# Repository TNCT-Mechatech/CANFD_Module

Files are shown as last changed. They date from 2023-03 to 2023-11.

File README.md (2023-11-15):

# CANFD_Module
SPI->CAN FDに変換するモジュール

名前:ひなた
※画像は最新のものと比較すると古い部分があります．git pullして基板データを確認してください．
<br>

<br>

PCBAは[production/PCBA](production/PCBA)を参照してJLCPCBに発注してください．

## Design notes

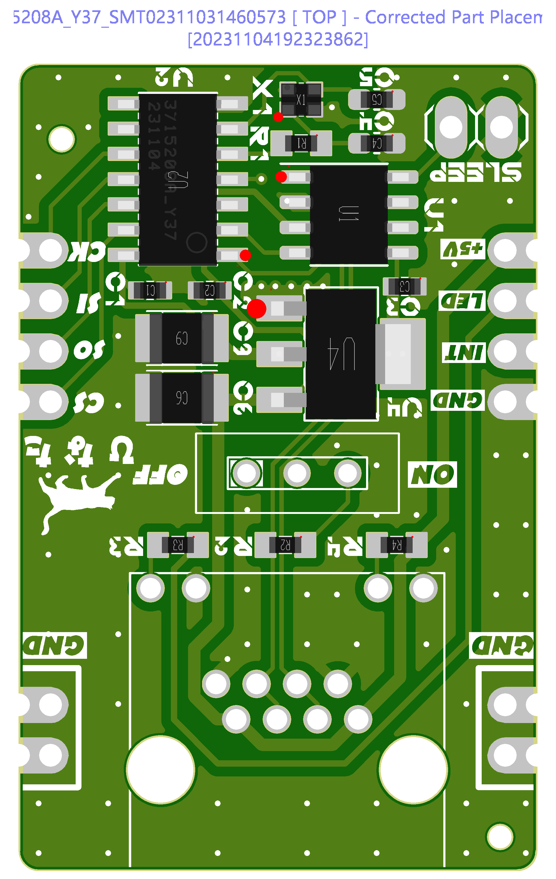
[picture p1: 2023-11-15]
production/PCBA/Produce_DanZhi.SMT_Snapshot.Top.3715208A_Y37.SMT02311031460573.png

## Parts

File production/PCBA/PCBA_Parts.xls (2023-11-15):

Comment | Designator | Footprint | JLCPCB Part # | 黄色で示す部品は名前間違ってます
MCP2517FD | U2 | MCP2517FD | C512185 | JLCPCB Partの欄に書かれている部品が正しいです
AZ1117CH-3.3TRG1 | U4 | AZ1117C | C92102 | JLCPCB Partの欄の部品で発注してください．
120Ω | R2 | CR0603 | C22787
0 | R1 | CR0603 | C21189
150 | R3,R4 | CR0603 | C22808
GRM32ER71E226KE15 | C6,C9 | 3225M | C21397
GRM0225C1E6R0BA03L | C4,C5 | 0603 | C426066
XRCGB40M000F4M01R0 | X1 | XRCGB40M000F4M00R0 | C485379
GCM188L81H104KA57 | C1,C2,C3 | GCM188L81H104KA57 | C161181
MCP2558FD | U1 | SOP-8_3.9x4.9mm_P1.27mm | C124015

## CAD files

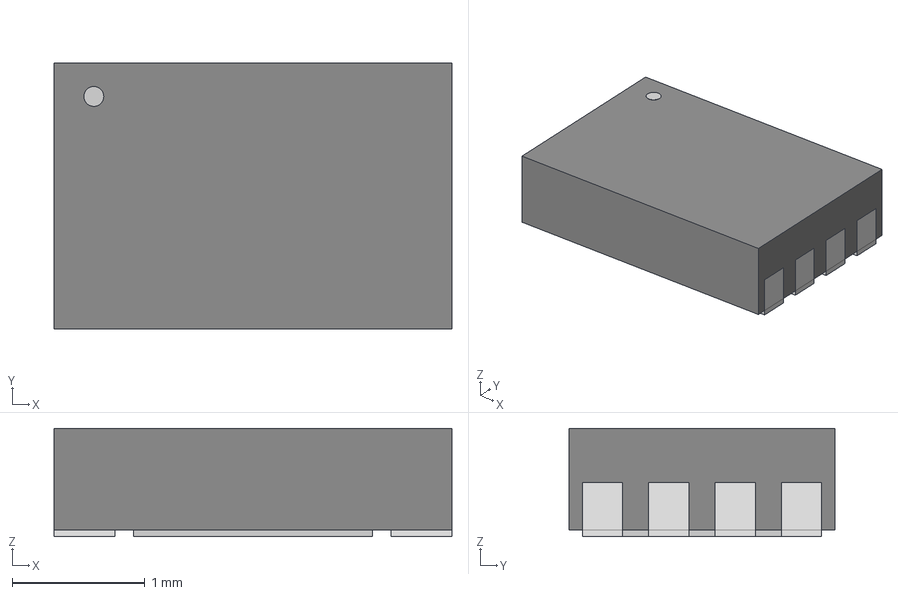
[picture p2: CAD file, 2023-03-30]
3dmodels/TDFN8_MNY_MCH.step
3.00 x 2.01 x 0.815 mm

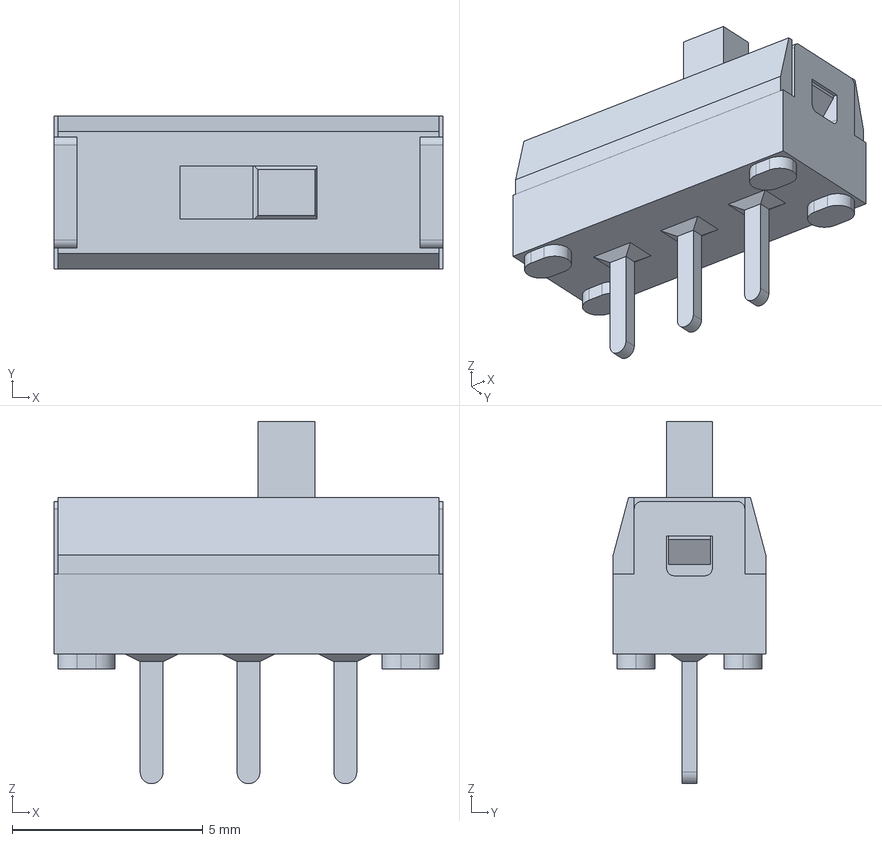
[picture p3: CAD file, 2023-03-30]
3dmodels/ss-12sdp2.stp
10.2 x 4.00 x 9.50 mm

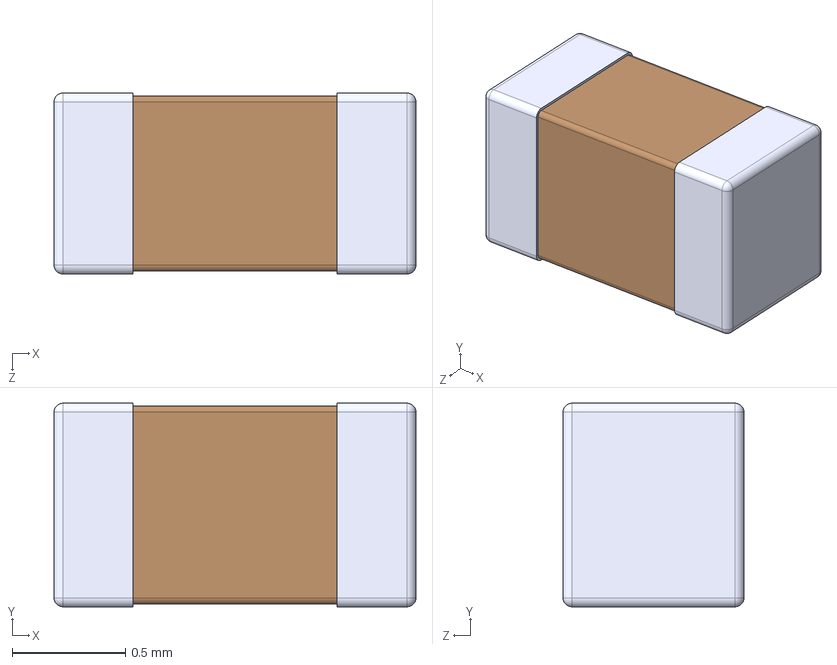
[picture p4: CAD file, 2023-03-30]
3dmodels/GCM188L81H104KA57D.step
1.60 x 0.9 x 0.8 mm

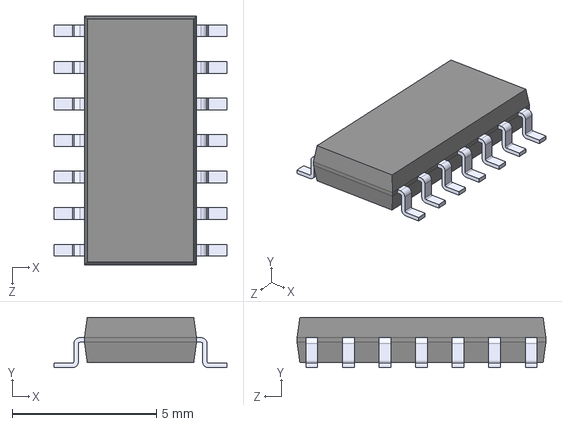
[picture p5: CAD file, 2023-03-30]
3dmodels/MCP2517FD-H_SL.step
5.99 x 1.75 x 8.65 mm

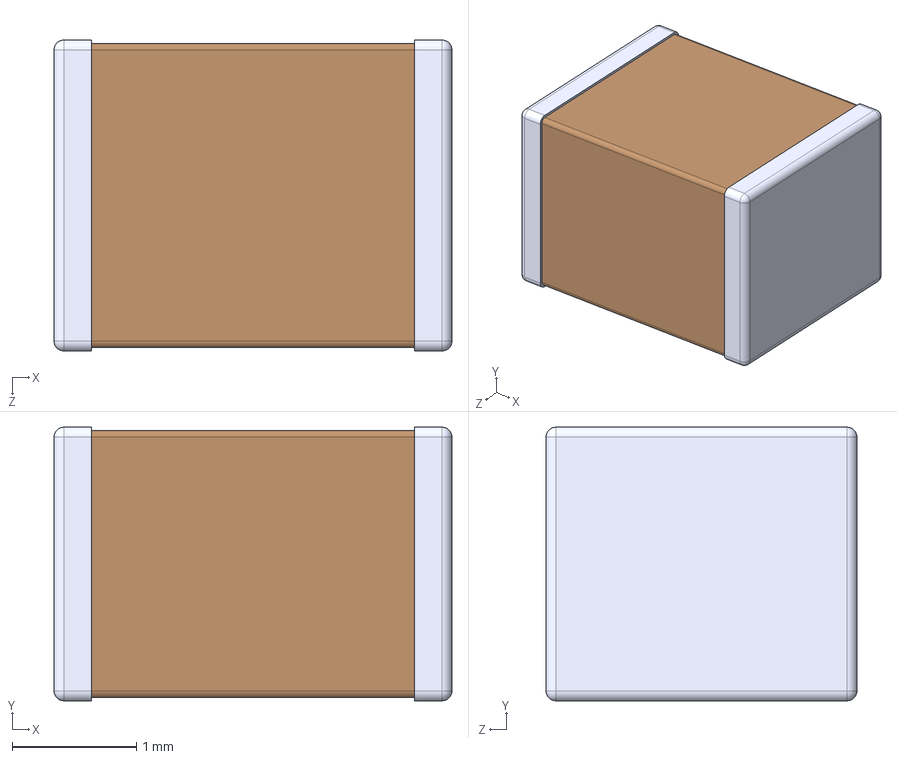
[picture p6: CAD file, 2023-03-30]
3dmodels/GRM32ER71H106KA12L.step
3.20 x 2.20 x 2.50 mm

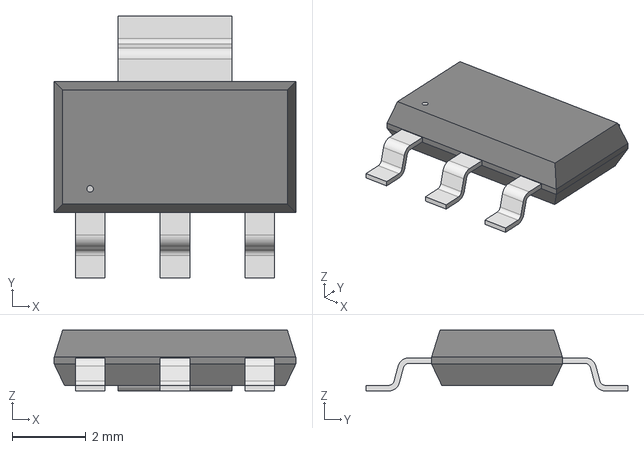
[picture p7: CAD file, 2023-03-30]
3dmodels/SOT-223_DIO.step
6.55 x 7.10 x 1.65 mm

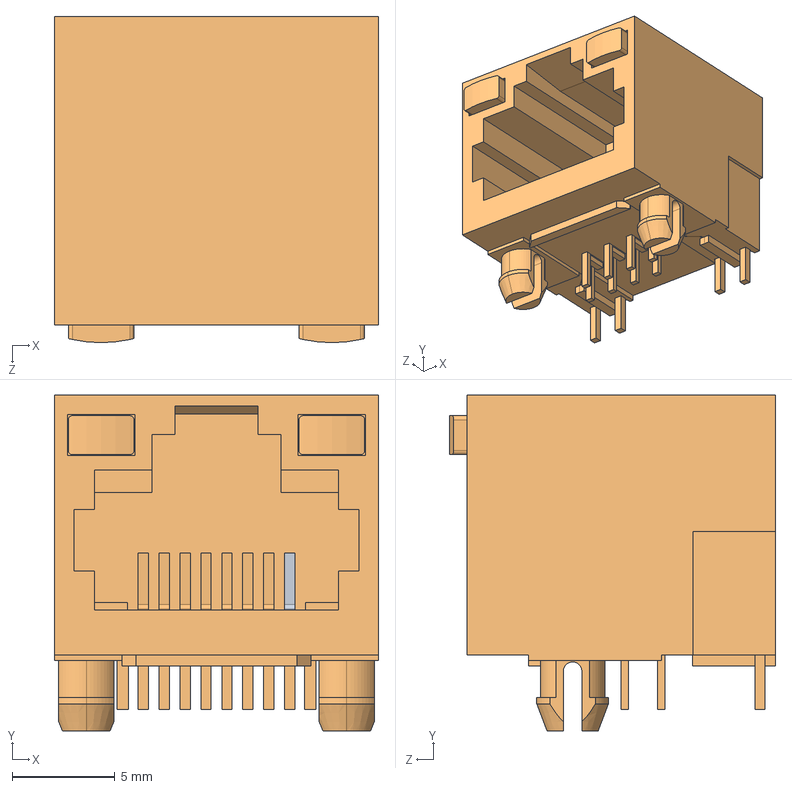
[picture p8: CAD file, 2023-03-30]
3dmodels/mtj-88arx1-lh-model (1).step
15.8 x 16.4 x 15.9 mm

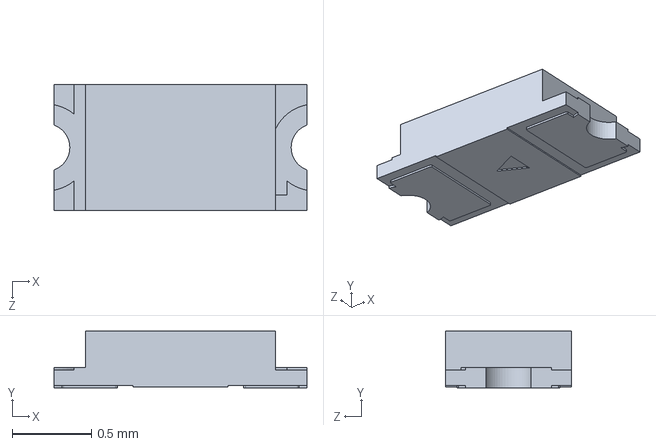
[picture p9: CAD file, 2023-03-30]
3dmodels/SMLE1.step
1.60 x 0.36 x 0.8 mm

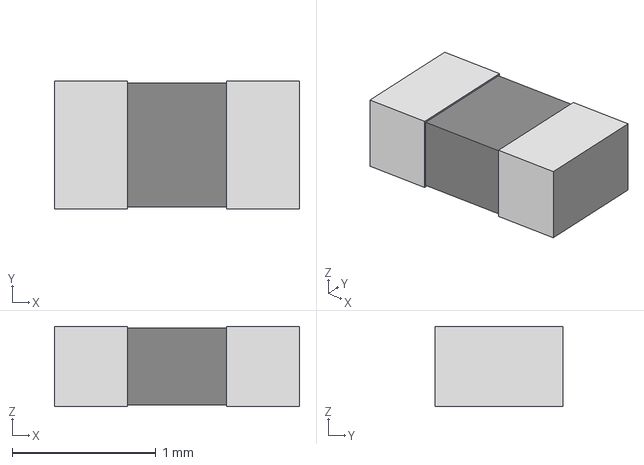
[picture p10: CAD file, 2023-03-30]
3dmodels/BO_CR0603.step
1.70 x 0.888 x 0.559 mm

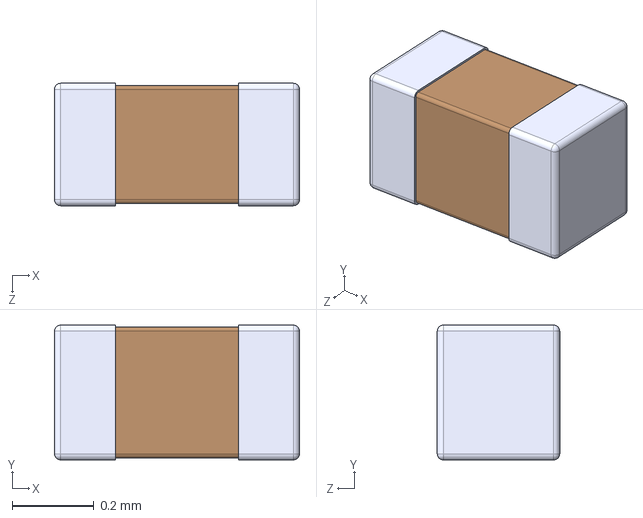
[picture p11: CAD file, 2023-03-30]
3dmodels/GRM0335C1H150FA01D.step
0.6 x 0.33 x 0.3 mm

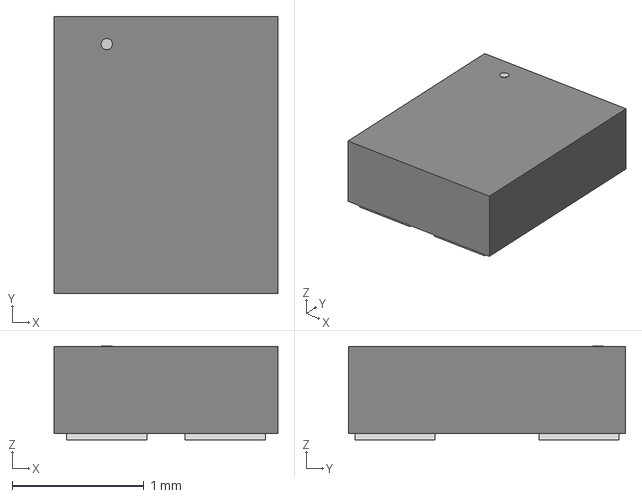
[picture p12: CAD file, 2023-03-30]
3dmodels/XRCGB40M000F1S2KR0_MUR.step
1.70 x 2.11 x 0.714 mm

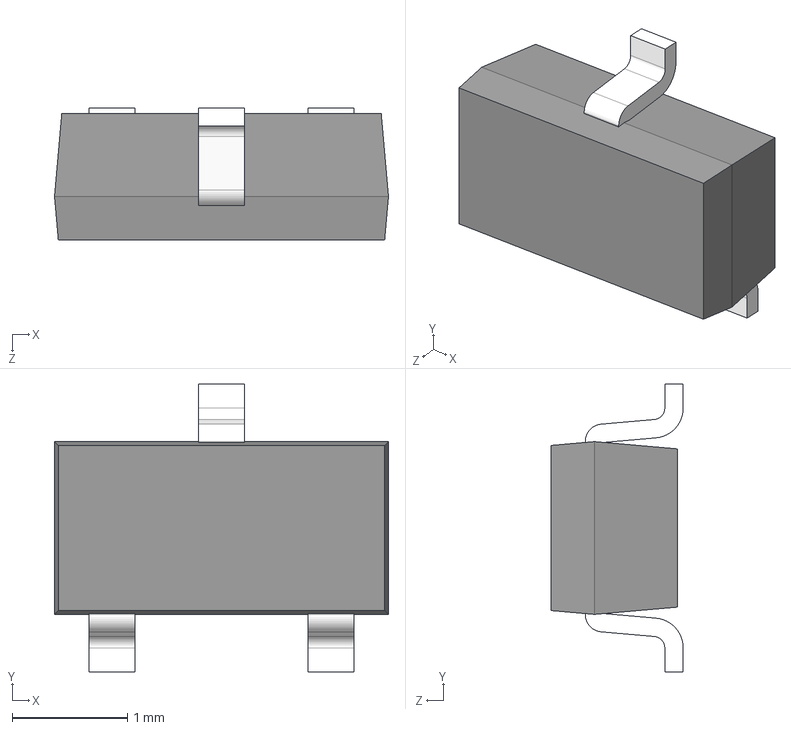
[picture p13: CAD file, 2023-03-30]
3dmodels/S-Mini-ZKN.STEP
2.90 x 2.50 x 1.15 mm

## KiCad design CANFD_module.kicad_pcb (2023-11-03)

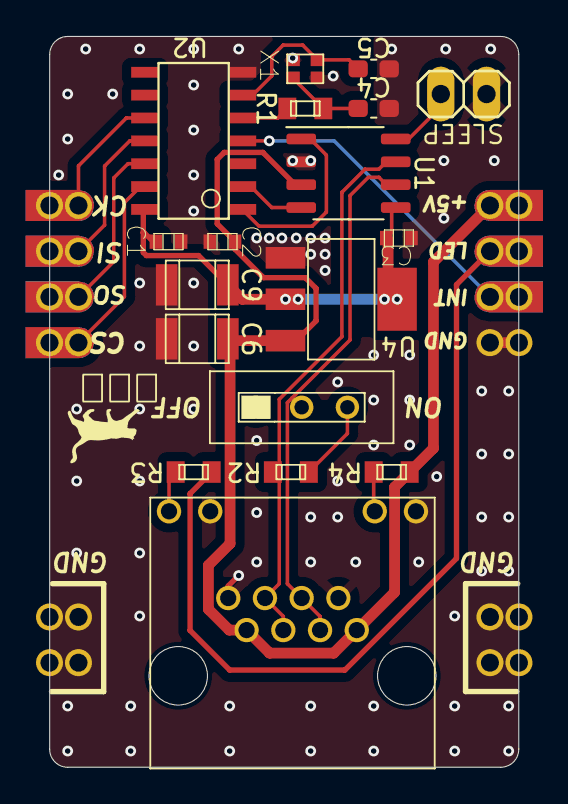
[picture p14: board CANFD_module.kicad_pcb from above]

Board: 2 copper layers, 26.1 x 40.6 mm, 22 parts (0 on the bottom side), 20 nets.

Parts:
C1, C2, C3: GCM188L81H104KA57
C4, C5: GRM0225C1E6R0BA03L; C_0603_1608Metric_Pad1.08x0.95mm_HandSolder
C6, C9: GRM32ER71E226KE15; 3225M
JP2, JP3: PINHEAD(4)_RASPICO; 1X04
JP4, JP5: PINHEAD(2)_RASPICO; PINHEAD_2_RASPICO
R1: 0; CR0603
R2: 120Ω; CR0603
R3, R4: 150; CR0603
RJ45_1: MTJ-88ARX1-LH
SLEEP: PINHD-1X2; 1X02
SW1: SS-12SDP2
U1: MCP2558FD; SOP-8_3.9x4.9mm_P1.27mm
U2: MCP2517FD
U4: AZ1117CH-3.3TRG1; AZ1117C
X1: XRCGB40M000F4M01R0; XRCGB40M000F4M00R0

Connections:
+3V3: C1.P$1, C3.P$1, C9.L (1), U1.5 (VIO), U2.VDD, U4.OUTPUT, U4.VOUT (OUTPUT)
+5V: C2.P$1, C6.L (1), JP2.PIN1 (1), JP2.PIN1_ (1), R4.RIGHT, RJ45_1.1, RJ45_1.7, U1.3 (VDD), U4.INPUT
/CAN+: R2.RIGHT, RJ45_1.5, RJ45_1.6, U1.7 (CANH)
/CAN-: RJ45_1.3, RJ45_1.4, SW1.C, U1.6 (CANL)
/COM_LED: JP2.PIN2 (2), JP2.PIN2_ (2), R3.LEFT
/CS: JP3.PIN1 (1), JP3.PIN1_ (1), U2.NCS
/INT: JP2.PIN3 (3), JP2.PIN3_ (3), U2.INT
/MISO: JP3.PIN2 (2), JP3.PIN2_ (2), U2.SDO
/MOSI: JP3.PIN3 (3), JP3.PIN3_ (3), U2.SDI
/SCK: JP3.PIN4 (4), JP3.PIN4_ (4), U2.SCK
GND: C1.P$2, C2.P$2, C3.P$2, C4.2, C5.2, C6.R (2), C9.R (2), JP2.PIN4 (4), JP2.PIN4_ (4), JP4.PIN1 (1), JP4.PIN1_ (1), JP4.PIN2 (2), JP4.PIN2_ (2), JP5.PIN1 (1), JP5.PIN1_ (1), JP5.PIN2 (2), JP5.PIN2_ (2), RJ45_1.2, RJ45_1.8, RJ45_1.LED1_K, RJ45_1.LED2_K, SLEEP.1, U1.2 (VSS), U2.VSS, U4.GND, X1.NC1, X1.NC2
unnamed: C4.1, R1.RIGHT, X1.2
unnamed: C5.1, U2.OSC1, X1.1
unnamed: R1.LEFT, U2.OSC2
unnamed: R2.LEFT, SW1.R
unnamed: R3.RIGHT, RJ45_1.LED1_A
unnamed: R4.LEFT, RJ45_1.LED2_A
unnamed: U1.4 (RXD), U2.RXCAN
unnamed: SLEEP.2, U1.8 (S)
unnamed: U1.1 (TXD), U2.TXCAN

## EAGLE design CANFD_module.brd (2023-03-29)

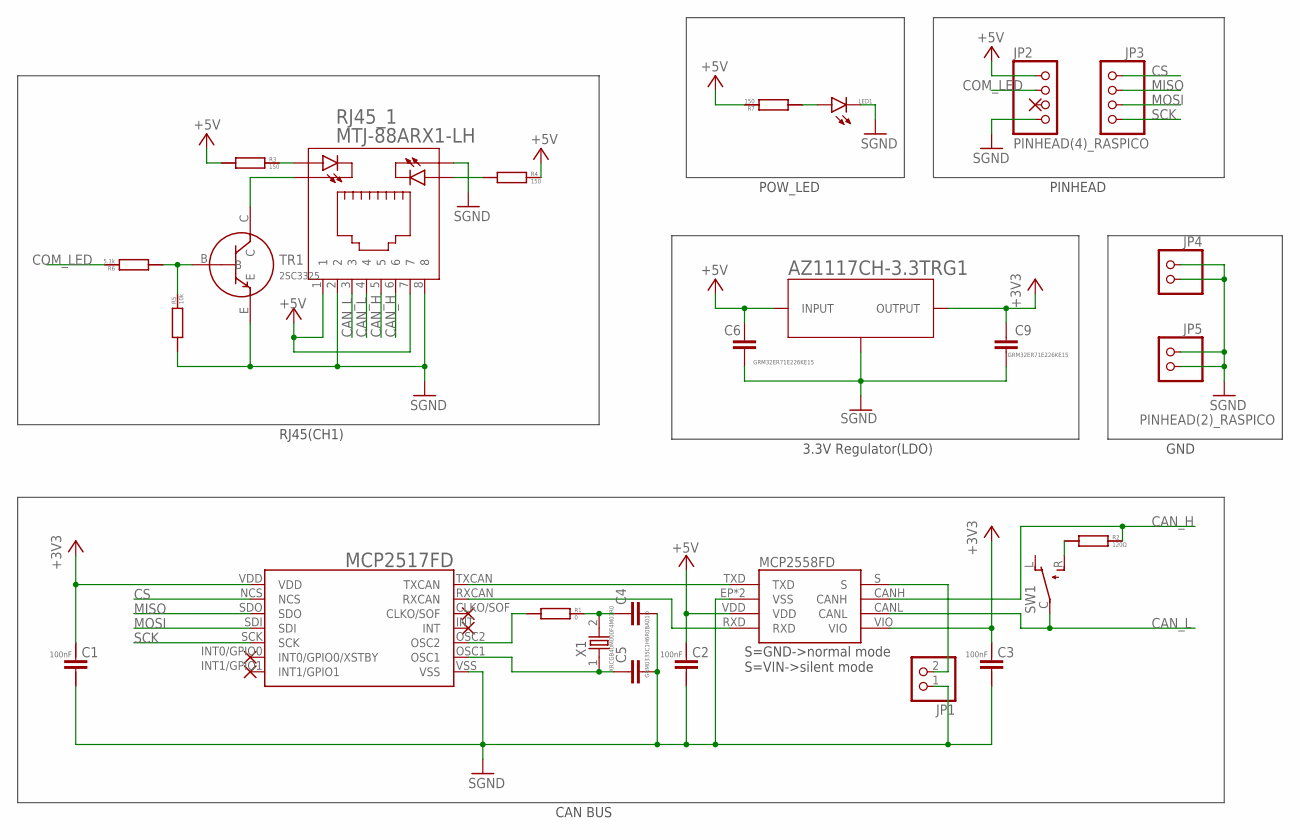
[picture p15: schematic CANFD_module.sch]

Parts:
C1, C2, C3: GCM188L81H104KA57
C4, C5: GRM0335C1H6R0BA01D; GRM0335C1H120GA01
C6, C9: GRM32ER71E226KE15; 3225M
JP1: PINHD-1X2; 1X02
JP2, JP3: PINHEAD(4)_RASPICO; 1X04
JP4, JP5: PINHEAD(2)_RASPICO; PINHEAD_2_RASPICO
LED1: SML-E12V8WT86
R1: 0; CR0603
R2: 120Ω; CR0603
R3, R4, R7: 150; CR0603
R5: 10k; CR0603
R6: 5.1k; CR0603
RJ45_1: MTJ-88ARX1-LH
SW1: SS-12SDP2
TR1: 2SC3325
U2: MCP2517FD
U$1: MCP2558FD
U$4: AZ1117CH-3.3TRG1; AZ1117C
X1: XRCGB40M000F4M01R0; XRCGB40M000F4M00R0

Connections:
+3V3: C1.P$1, C3.P$1, C9.L (1), U2.VDD, U$1.VIO, U$4.OUTPUT, U$4.VOUT (OUTPUT)
+5V: C2.P$1, C6.L (1), JP2.PIN1 (1), JP2.PIN1_ (1), R3.LEFT, R4.RIGHT, R7.RIGHT, RJ45_1.1, RJ45_1.7, U$1.VDD, U$4.INPUT
CAN_H: R2.RIGHT, RJ45_1.5, RJ45_1.6, U$1.CANH
CAN_L: RJ45_1.3, RJ45_1.4, SW1.C, U$1.CANL
COM_LED: JP2.PIN2 (2), JP2.PIN2_ (2), R6.RIGHT
CS: JP3.PIN1 (1), JP3.PIN1_ (1), U2.NCS
MISO: JP3.PIN2 (2), JP3.PIN2_ (2), U2.SDO
MOSI: JP3.PIN3 (3), JP3.PIN3_ (3), U2.SDI
unnamed: LED1.A, R7.LEFT
unnamed: R2.LEFT, SW1.R
unnamed: U2.TXCAN, U$1.TXD
unnamed: U2.RXCAN, U$1.RXD
unnamed: R1.LEFT, U2.OSC2
unnamed: C5.1, U2.OSC1, X1.1
unnamed: C4.1, R1.RIGHT, X1.2
unnamed: R4.LEFT, RJ45_1.LED2_A
unnamed: JP1.2, U$1.S
unnamed: R3.RIGHT, RJ45_1.LED1_A
unnamed: RJ45_1.LED1_K, TR1.C
unnamed: R5.RIGHT, R6.LEFT, TR1.B
SCK: JP3.PIN4 (4), JP3.PIN4_ (4), U2.SCK
SGND: C1.P$2, C2.P$2, C3.P$2, C4.2, C5.2, C6.R (2), C9.R (2), JP1.1, JP2.PIN4 (4), JP2.PIN4_ (4), JP4.PIN1 (1), JP4.PIN1_ (1), JP4.PIN2 (2), JP4.PIN2_ (2), JP5.PIN1 (1), JP5.PIN1_ (1), JP5.PIN2 (2), JP5.PIN2_ (2), LED1.K (C), R5.LEFT, RJ45_1.2, RJ45_1.8, RJ45_1.LED2_K, TR1.E, U2.VSS, U$1.EP (VSS), U$1.VSS, U$4.GND

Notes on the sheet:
S=GND->normal mode S=VIN->silent mode
CAN BUS
RJ45(CH1)
3.3V Regulator(LDO)
PINHEAD
POW_LED
GND

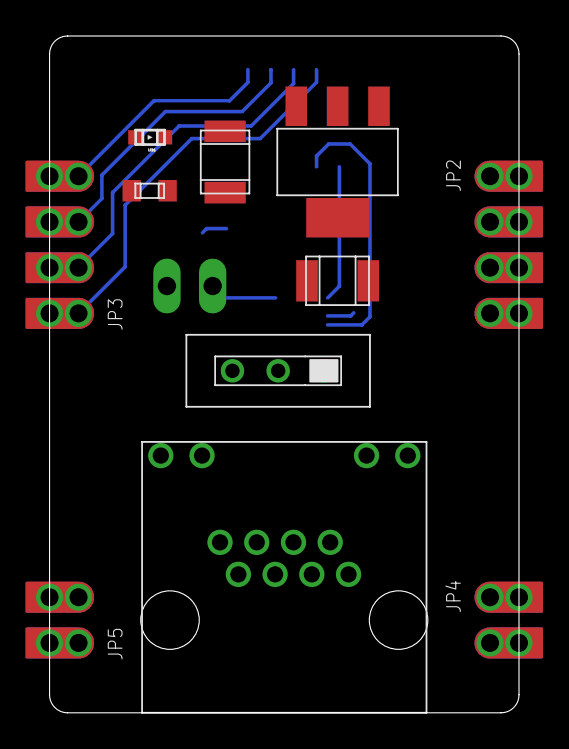
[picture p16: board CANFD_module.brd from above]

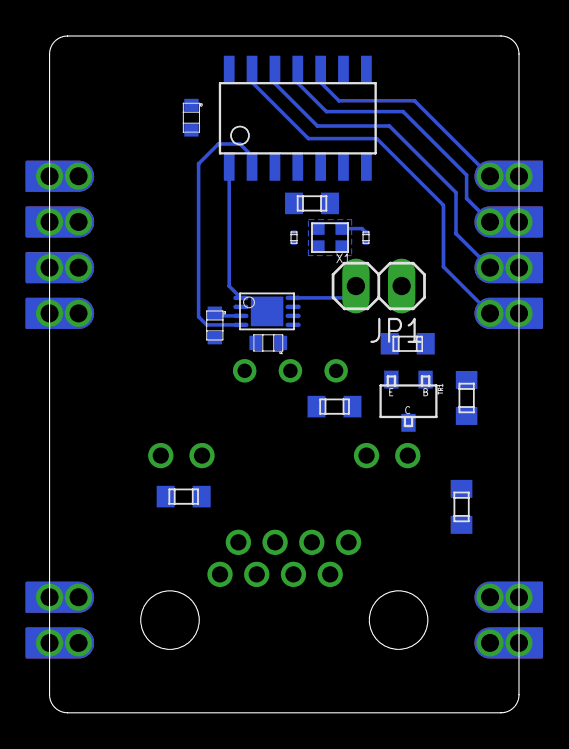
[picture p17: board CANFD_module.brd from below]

Board: 2 copper layers, 26.1 x 37.6 mm, 27 parts (16 on the bottom side), 22 nets.

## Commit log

2023-03-29 途中まで
    [CANFD_module.brd, CANFD_module.sch]
2023-03-30 基板完成
    [BO_CR0603.step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]
2023-03-30 基板微修正
2023-10-22 [fix]0603->1608 package
    [CANFD_module-B_Cu.gbr, CANFD_module-B_Mask.gbr, CANFD_module-B_Paste.gbr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]
2023-11-03 [fix]ピンアサインをver1.0と同じにした
    [BO_CR0603.step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]
2023-11-03 [fix]versionの表示
    [BO_CR0603.step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]
2023-11-15 [add]PCBA用のBOMを追加
    [PCBA_Parts.xls]
2023-11-15 rm ignore files
    [CANFD_module-NPTH.drl, CANFD_module-PTH.drl, CANFD_module.drl]
2023-11-15 rm gerber files
    [CANFD_module-B_Cu.gbr, CANFD_module-B_Mask.gbr, CANFD_module-B_Paste.gbr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]
